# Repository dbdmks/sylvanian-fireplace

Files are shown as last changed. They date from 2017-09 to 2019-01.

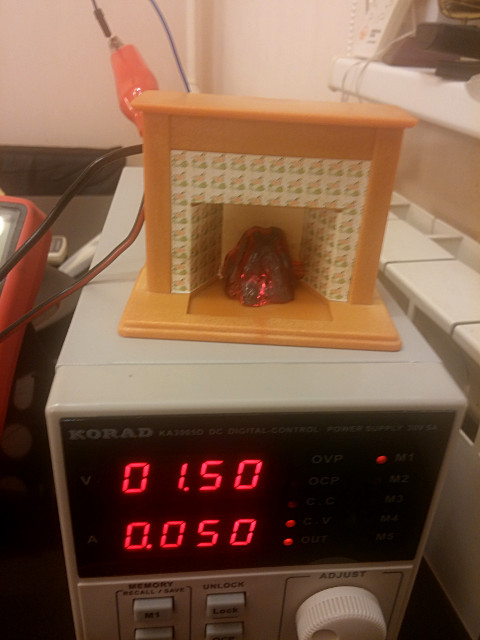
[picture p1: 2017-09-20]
images/incandecent1.5v.jpg

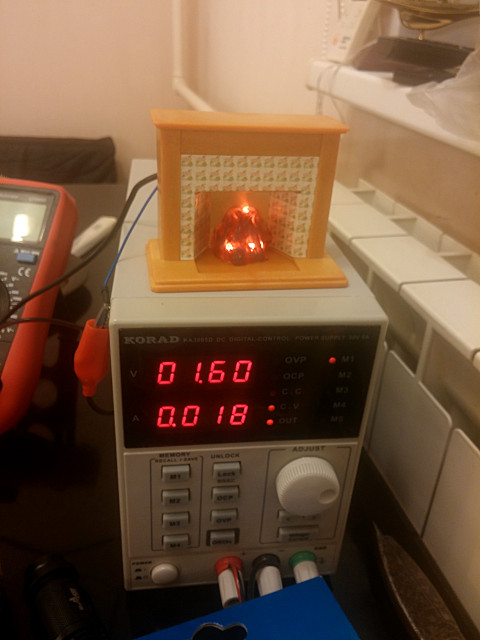
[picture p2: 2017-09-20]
images/3led1.6v.jpg

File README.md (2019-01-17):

## Sylvanian fireplace LED mod. ##

A controller to save battery in the [Sylvanian Families fireplace][1]

It originally uses small incandescent lamp and simple slide switch. 
This leads to battery is completely depleted it 1 day if you have forget to turn it off.

I have changed this small incandecent to 3 ultrabright warm white LEDs and added:
- step-up converter (5V though, the one I had by hand, use 3.3V if you have a choice, for a better efficiency)
- STM8 controller (small STM8S103F3P9 board from Aliexpress)
- 3pcs 100ohm resistors
- peice of bluetack to get rid of white light coming out between the fire and bottom of the fireplace

[Here][6] is the layout of components inside the fireplace.

The device runs at [high brightness][2] flickering and emulating burning fire for 30 minutes.
After this top LED light is [dimmed][3] for 1.5 minutes until off.
Then both bottom LEDs are dimmed for 15 minutes to constant [weak glow][4], 
which will then be [disabled completely][5] and uC put into halt mode consuming less than 1mA.

There are binary `sfp.s19` and `option_bytes.hex` files in the `Release` directory, you also can use `sft_programmer.stp` file to just flash the firmware.

If you wish to generate your own brightness curves - use the Gnuplot: `gnuplot -c plot.gp` which will create `out_candle.dat`, then run `convert.pl` perl script to convert this into `pwm_waves.h` header file.

There's also `candle.gp` gnuplot file which can be used to generate smooth splines through points from `manual.dat`. But it's either too slow to look like a fire or too many points should be added to the file manually.

---
### A video how it looks like: ###
preview video (http://www.youtube.com/watch?v=3CJmpJ_zcQg)

[1]:http://sylvanianfamilies.net/uk/catalog/item_detail.php?product_id=572
[2]:images/3led1.6v.jpg
[3]:images/2leds1.6v.jpg
[4]:images/2leds_glow1.6v.jpg 
[5]:images/sleeping.jpg
[6]:images/layout.jpg

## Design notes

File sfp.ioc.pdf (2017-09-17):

sfp Project
Configuration Report

## 1. Description

1.1. Project
Project Name | sfp
Board Name | No information
Generated with: | STM8CubeMX 1.1.0
Date | 09/17/2017
1.2. MCU
MCU Series | STM8S
MCU Line | STM8S103/105
MCU name | STM8S103F3Px
MCU Package | TSSOP20
MCU Pin number | 20

## 2. Pinout Configuration

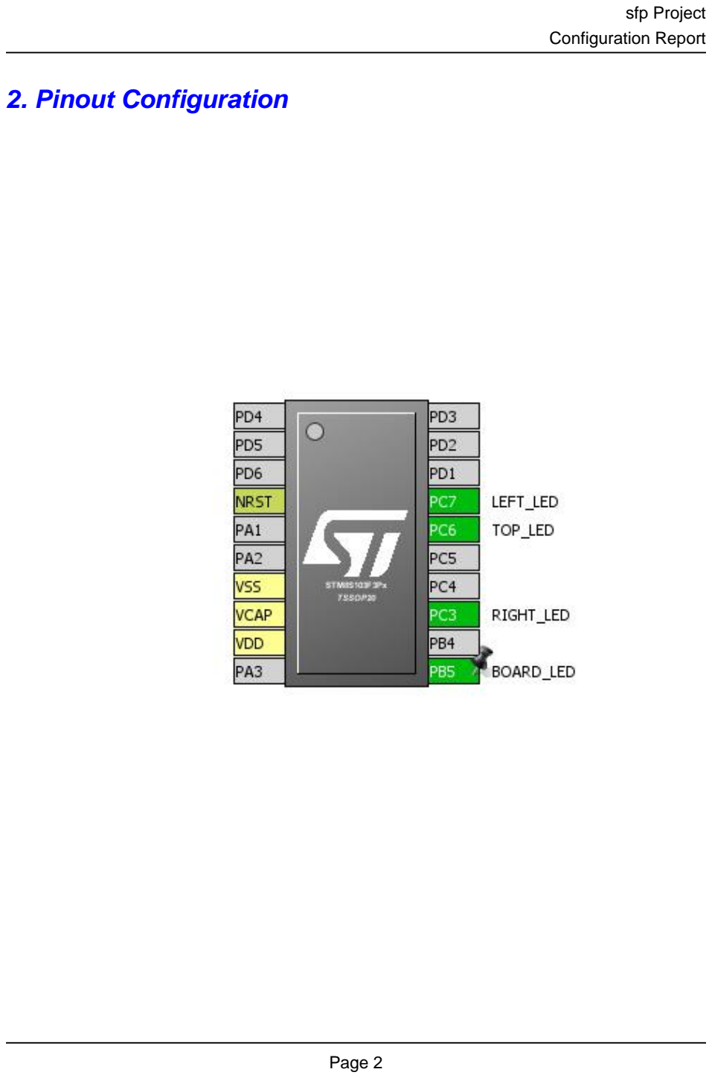
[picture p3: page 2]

## 3. Pins Configuration

Pin Number TSSOP20 | Pin Name (function after reset) | Pin Type | Alternate Function(s) | Label
4 | NRST | Reset
7 | VSS | Power
8 | VCAP | Power
9 | VDD | Power
11 | PB5 * | I/O | GPIO_Output | BOARD_LED
13 | PC3 | I/O | TIM1_CH3 | RIGHT_LED
16 | PC6 | I/O | TIM1_CH1 | TOP_LED
17 | PC7 | I/O | TIM1_CH2 | LEFT_LED

* The pin is affected with an I/O function

## 4. Clock Tree Configuration

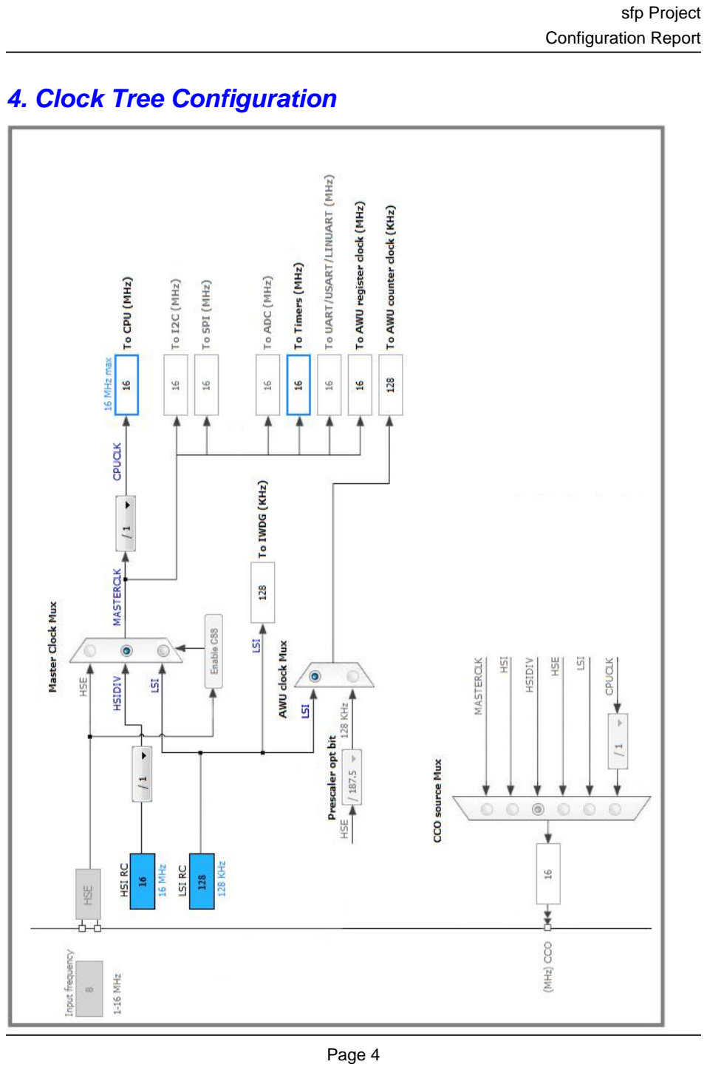
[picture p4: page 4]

## 5. Power Consumption Calculator report

5.1. Microcontroller Selection
Series | STM8S
Line | STM8S103/105
MCU | STM8S103F3Px
Datasheet | 15441_Rev13
5.2. Parameter Selection
Temperature | 25
Vdd | 3.3
5.3. Battery Selection
Battery | Alkaline(AAA LR03)
Capacity | 1250.0 mAh
Self Discharge | 0.3 %/month
Nominal Voltage | 1.5 V
Max Cont Current | 400.0 mA
Max Pulse Current | 0.0 mA
Cells in series | 1
Cells in parallel | 1

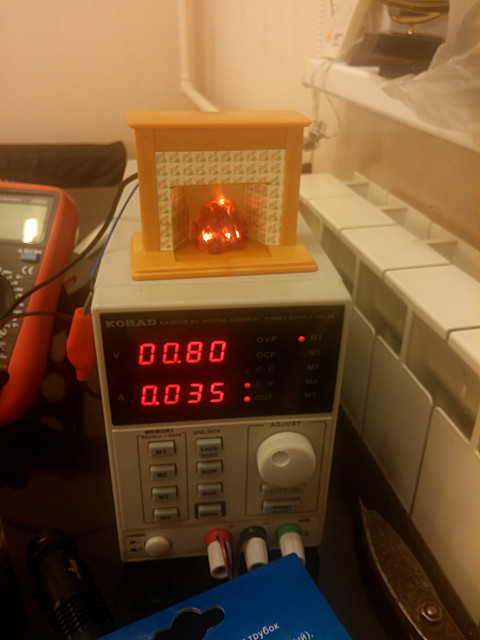
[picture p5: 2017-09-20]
images/3leds0.8v.jpg

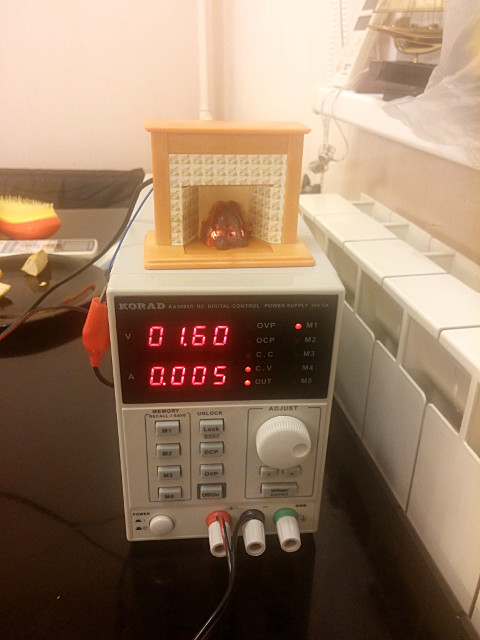
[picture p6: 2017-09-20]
images/2leds_glow1.6v.jpg

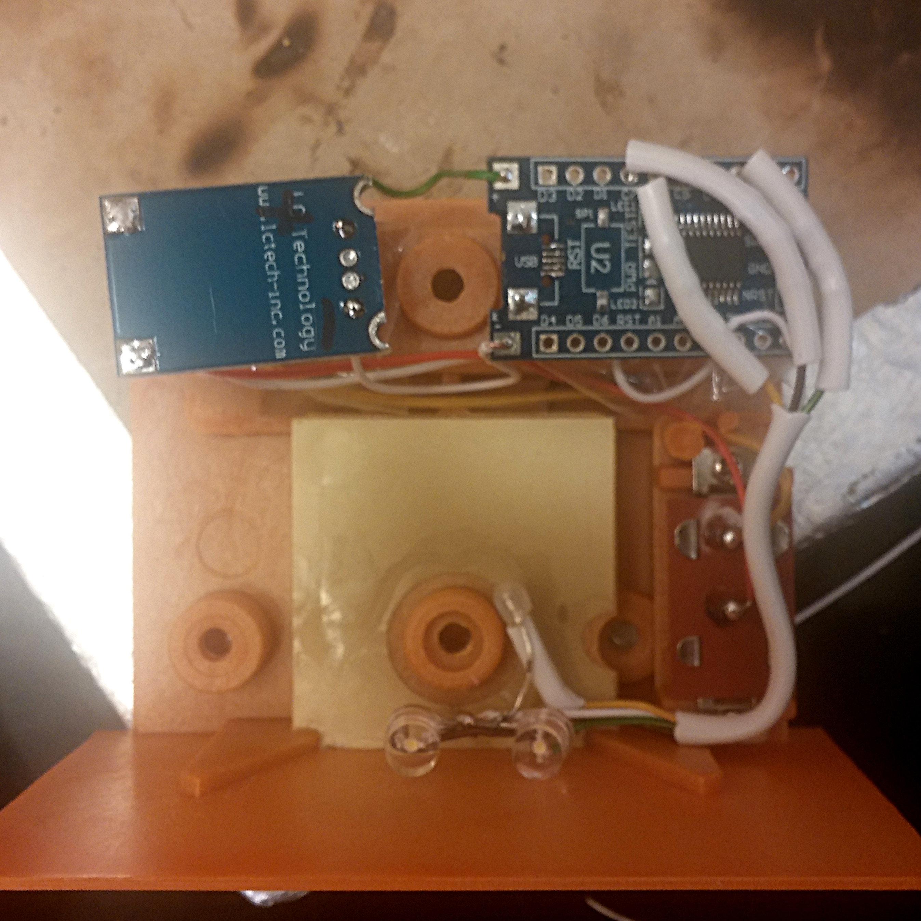
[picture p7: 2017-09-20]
images/layout.jpg

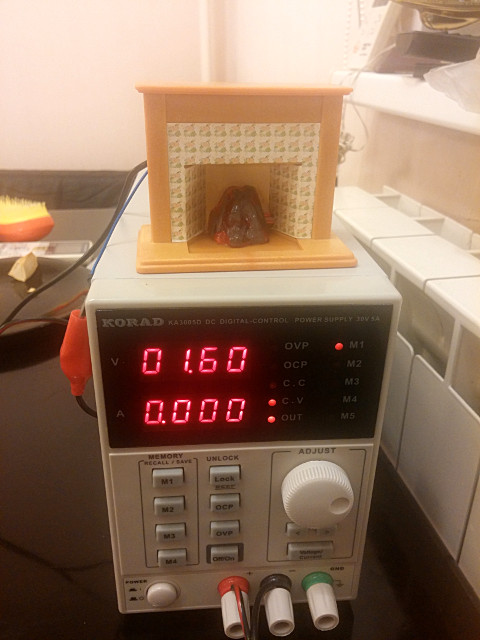
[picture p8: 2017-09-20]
images/sleeping.jpg

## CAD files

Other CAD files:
sfp_Programmer/sfp_STVP.stp
sfp_programmer_project.stp
sfp.stp

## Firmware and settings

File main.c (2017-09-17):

/* MAIN.C file
 * 
 * Copyright (c) 2002-2005 STMicroelectronics
 */
#include <stm8s.h>


void Delay(uint16_t count);
static void TIM1_pwm_setup(void);
static void TIM2_wakeup_setup(void); //1032/2mhz/64psc = reload in ~33ms
static void GoGreen(void);

main()
{  
	CLK_DeInit();
	GoGreen();
  CLK_HSIPrescalerConfig(CLK_PRESCALER_HSIDIV1);
	
	GPIO_Init(GPIOA,GPIO_PIN_ALL,GPIO_MODE_IN_PU_NO_IT);
	GPIO_Init(GPIOB,GPIO_PIN_ALL,GPIO_MODE_IN_PU_NO_IT);
	GPIO_Init(GPIOC,GPIO_PIN_ALL&~(GPIO_PIN_3|GPIO_PIN_6|GPIO_PIN_7),GPIO_MODE_IN_PU_NO_IT);
	GPIO_Init(GPIOD,GPIO_PIN_ALL,GPIO_MODE_IN_PU_NO_IT);
	
	//GPIO_Init(GPIOB,GPIO_PIN_5,GPIO_MODE_OUT_OD_HIZ_SLOW); //onboard LED
	
	TIM1_pwm_setup();
	TIM2_wakeup_setup();
	CFG->GCR |= CFG_GCR_AL;
  //while(1);
	wfi();
	halt();
}

static void GoGreen(void) {
	CLK->PCKENR1 = (1<<CLK_PERIPHERAL_TIMER1) | (1<<CLK_PERIPHERAL_TIMER2);
	CLK->PCKENR2 = 0;
}

static void TIM2_wakeup_setup(void) {
	TIM2_DeInit();
	TIM2_TimeBaseInit(TIM2_PRESCALER_2048, 235); //~30ms
	TIM2_UpdateRequestConfig(TIM2_UPDATESOURCE_GLOBAL);
	TIM2_UpdateDisableConfig(DISABLE);
	TIM2_ITConfig(TIM2_IT_UPDATE, ENABLE);
	enableInterrupts();
	TIM2_Cmd(ENABLE);
}


static void TIM1_pwm_setup(void) {
	TIM1_DeInit();
	TIM1_TimeBaseInit(0, TIM1_COUNTERMODE_UP, 99, 0);
	TIM1_OC1Init(TIM1_OCMODE_PWM2, 
							 TIM1_OUTPUTSTATE_ENABLE, 
							 TIM1_OUTPUTNSTATE_DISABLE,
							 100,
							 TIM1_OCPOLARITY_HIGH,
							 TIM1_OCNPOLARITY_LOW,
							 TIM1_OCIDLESTATE_RESET,
							 TIM1_OCNIDLESTATE_RESET);
	
	TIM1_OC2Init(TIM1_OCMODE_PWM2, 
							 TIM1_OUTPUTSTATE_ENABLE, 
							 TIM1_OUTPUTNSTATE_DISABLE,
							 100,
							 TIM1_OCPOLARITY_HIGH,
							 TIM1_OCNPOLARITY_LOW,
							 TIM1_OCIDLESTATE_RESET,
							 TIM1_OCNIDLESTATE_RESET);
							 
	TIM1_OC3Init(TIM1_OCMODE_PWM2, 
							 TIM1_OUTPUTSTATE_ENABLE, 
							 TIM1_OUTPUTNSTATE_DISABLE,
							 100,
							 TIM1_OCPOLARITY_HIGH,
							 TIM1_OCNPOLARITY_LOW,
							 TIM1_OCIDLESTATE_RESET,
							 TIM1_OCNIDLESTATE_RESET);
	TIM1_Cmd(ENABLE);
	TIM1_CtrlPWMOutputs(ENABLE);

	
}

void Delay(uint16_t count) {
	while (count--);
}


#ifdef USE_FULL_ASSERT
/**
  * @brief  Reports the name of the source file and the source line number
  *   where the assert_param error has occurred.
  * @param file: pointer to the source file name
  * @param line: assert_param error line source number
  * @retval None
  */
void assert_failed(uint8_t* file, uint32_t line)
{ 
  /* User can add his own implementation to report the file name and line number,
     ex: printf("Wrong parameters value: file %s on line %d\r\n", file, line) */

  /* Infinite loop */
  while (1)
  {
  }
}
#endif

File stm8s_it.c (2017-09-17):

/**
  ******************************************************************************
  * @file    stm8s_it.c
  * @author  MCD Application Team
  * @version  V2.2.0
  * @date     30-September-2014
  * @brief   This file contains all the interrupt routines.
  ******************************************************************************
  * @attention
  *
  * <h2><center>&copy; COPYRIGHT 2014 STMicroelectronics</center></h2>
  *
  * Licensed under MCD-ST Liberty SW License Agreement V2, (the "License");
  * You may not use this file except in compliance with the License.
  * You may obtain a copy of the License at:
  *
  *        http://www.st.com/software_license_agreement_liberty_v2
  *
  * Unless required by applicable law or agreed to in writing, software 
  * distributed under the License is distributed on an "AS IS" BASIS, 
  * WITHOUT WARRANTIES OR CONDITIONS OF ANY KIND, either express or implied.
  * See the License for the specific language governing permissions and
  * limitations under the License.
  *
  ******************************************************************************
  */ 

/* Includes ------------------------------------------------------------------*/
#include "stm8s_it.h"
#include "pwm_waves.h"

/* Private typedef -----------------------------------------------------------*/
typedef  void (*Function_Pointer)(void);

/* Private define ------------------------------------------------------------*/
/* Private macro -------------------------------------------------------------*/
/* Private variables ---------------------------------------------------------*/
/* Private function prototypes -----------------------------------------------*/
void Sleep(void);
uint8_t CalculateFadeout(uint8_t brightness, uint8_t fadeout);
uint8_t CalculateFadeoutTop(uint8_t brightness, uint8_t fadeout);

/* Private functions ---------------------------------------------------------*/
void Sleep(void) {
	TIM1_SetCompare3(100);
	TIM1_SetCompare2(100);
	TIM1_SetCompare1(100);	
	TIM1_CtrlPWMOutputs(DISABLE);
	TIM1_Cmd(DISABLE);
	TIM2_Cmd(DISABLE);
  halt();
}
uint8_t CalculateFadeout(uint8_t brightness, uint8_t fadeout) {
	brightness += fadeout;
	return (brightness > 100) ? 95 : brightness;
}

uint8_t CalculateFadeoutTop(uint8_t brightness, uint8_t fadeout) {
	brightness += fadeout;
	return (brightness > 100) ? 100 : brightness;
}

/* Public functions ----------------------------------------------------------*/

/** @addtogroup RST_IllegalOpcode
  * @{
  */
#ifdef _COSMIC_
/**
  * @brief  Dummy interrupt routine
  * @param  None
  * @retval None
  */
INTERRUPT_HANDLER(NonHandledInterrupt, 25)
{
  /* In order to detect unexpected events during development,
     it is recommended to set a breakpoint on the following instruction.
  */
}
#endif /*_COSMIC_*/

/**
  * @brief  TRAP interrupt routine
  * @param  None
  * @retval None
  */
INTERRUPT_HANDLER_TRAP(TRAP_IRQHandler)
{
  /* In order to detect unexpected events during development,
     it is recommended to set a breakpoint on the following instruction.
  */
}
/**
  * @brief  Top Level Interrupt routine.
  * @param  None
  * @retval None
  */
INTERRUPT_HANDLER(TLI_IRQHandler, 0)
{
  /* In order to detect unexpected events during development,
     it is recommended to set a breakpoint on the following instruction.
  */
}

/**
  * @brief  Auto Wake Up Interrupt routine.
  * @param  None
  * @retval None
  */
INTERRUPT_HANDLER(AWU_IRQHandler, 1)
{
  /* In order to detect unexpected events during development,
     it is recommended to set a breakpoint on the following instruction.
  */
}

/**
  * @brief  Clock Controller Interrupt routine.
  * @param  None
  * @retval None
  */
INTERRUPT_HANDLER(CLK_IRQHandler, 2)
{
  /* In order to detect unexpected events during development,
     it is recommended to set a breakpoint on the following instruction.
  */
}

/**
  * @brief  External Interrupt PORTA Interrupt routine.
  * @param  None
  * @retval None
  */
INTERRUPT_HANDLER(EXTI_PORTA_IRQHandler, 3)
{
  /* In order to detect unexpected events during development,
     it is recommended to set a breakpoint on the following instruction.
  */
}

/**
  * @brief  External Interrupt PORTB Interrupt routine.
  * @param  None
  * @retval None
  */
INTERRUPT_HANDLER(EXTI_PORTB_IRQHandler, 4)
{
  /* In order to detect unexpected events during development,
     it is recommended to set a breakpoint on the following instruction.
  */
}

/**
  * @brief  External Interrupt PORTC Interrupt routine.
  * @param  None
  * @retval None
  */
INTERRUPT_HANDLER(EXTI_PORTC_IRQHandler, 5)
{
		Function_Pointer  Jump_Function;
		/* Jump to the illegal opcode address */
    Jump_Function = (Function_Pointer) 0x9FFF;
    Jump_Function();
}

/**
  * @brief  External Interrupt PORTD Interrupt routine.
  * @param  None
  * @retval None
  */
INTERRUPT_HANDLER(EXTI_PORTD_IRQHandler, 6)
{
  /* In order to detect unexpected events during development,
     it is recommended to set a breakpoint on the following instruction.
  */
}

/**
  * @brief  External Interrupt PORTE Interrupt routine.
  * @param  None
  * @retval None
  */
INTERRUPT_HANDLER(EXTI_PORTE_IRQHandler, 7)
{
  /* In order to detect unexpected events during development,
     it is recommended to set a breakpoint on the following instruction.
  */
}
#ifdef STM8S903
/**
  * @brief  External Interrupt PORTF Interrupt routine.
  * @param  None
  * @retval None
  */
 INTERRUPT_HANDLER(EXTI_PORTF_IRQHandler, 8)
{
  /* In order to detect unexpected events during development,
     it is recommended to set a breakpoint on the following instruction.
  */
}
#endif /*STM8S903*/

#ifdef STM8S208
/**
  * @brief  CAN RX Interrupt routine.
  * @param  None
  * @retval None
  */
 INTERRUPT_HANDLER(CAN_RX_IRQHandler, 8)
{
  /* In order to detect unexpected events during development,
     it is recommended to set a breakpoint on the following instruction.
  */
}

/**
  * @brief  CAN TX Interrupt routine.
  * @param  None
  * @retval None
  */
 INTERRUPT_HANDLER(CAN_TX_IRQHandler, 9)
{
  /* In order to detect unexpected events during development,
     it is recommended to set a breakpoint on the following instruction.
  */
}
#endif /*STM8S208 || STM8AF52Ax */

/**
  * @brief  SPI Interrupt routine.
  * @param  None
  * @retval None
  */
INTERRUPT_HANDLER(SPI_IRQHandler, 10)
{
  /* In order to detect unexpected events during development,
     it is recommended to set a breakpoint on the following instruction.
  */
}

/**
  * @brief  Timer1 Update/Overflow/Trigger/Break Interrupt routine.
  * @param  None
  * @retval None
  */
INTERRUPT_HANDLER(TIM1_UPD_OVF_TRG_BRK_IRQHandler, 11)
{
  /* In order to detect unexpected events during development,
     it is recommended to set a breakpoint on the following instruction.
  */
}
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

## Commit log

2017-09-14 timer works
    [sfp.stp]
2017-09-14 adjusted timers to 30ms
2017-09-15 added waveform for side leds
2017-09-16 waveforms playing
    [sfp.stp]
2017-09-17 Unused pins internal pullup
    [sfp.stp]
2017-09-17 Added option bytes, added STVisual Programmer project, disabled debug loop in main(), fixed unused pins initialization
    [sfp_STVP.stp, sfp_programmer_project.stp]
2017-09-19 Added autounlock setting to programmer settings
    [sfp_programmer_project.stp]

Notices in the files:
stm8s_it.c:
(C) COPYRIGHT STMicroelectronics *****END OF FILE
